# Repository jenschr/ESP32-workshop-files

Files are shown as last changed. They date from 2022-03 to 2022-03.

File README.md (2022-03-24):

# ESP32-workshop-files
Kicad files from my two-day workshop at [Bitraf](https://github.com/bitraf) on creating an ESP32 based IoT device from scratch. In the Workshop, attendees will be making an IoT device from scratch using the Open Source EDA software Kicad. [Slides from the workshop](https://www.slideshare.net/jensa/two-day-electronics-workshop-with-kicad-training) can be found at my Slideshare account.

## Reference designs
In the workshop, we'll create our own boards from scratch, but we found that it's convenient to have a project to compare and check things against. In the workshop, the attendees can choose to use either the ESP32 S2/S3 Mini or the ESP32 Wroom 32E modules. The latter requires the use of a serial chip such as the CP2102/04 and this tested design has the required auto-program circuitry.

## Alternate parts
Having a devboard is fun, but having some builtin input and output is even better, so for the attendees that don't have a plan, I've suggested to add an APA102 Dotstar pixel as well as a simple NTC-based temperature sensor. The circuit for these two are in the files for the S2/S3 Mini.

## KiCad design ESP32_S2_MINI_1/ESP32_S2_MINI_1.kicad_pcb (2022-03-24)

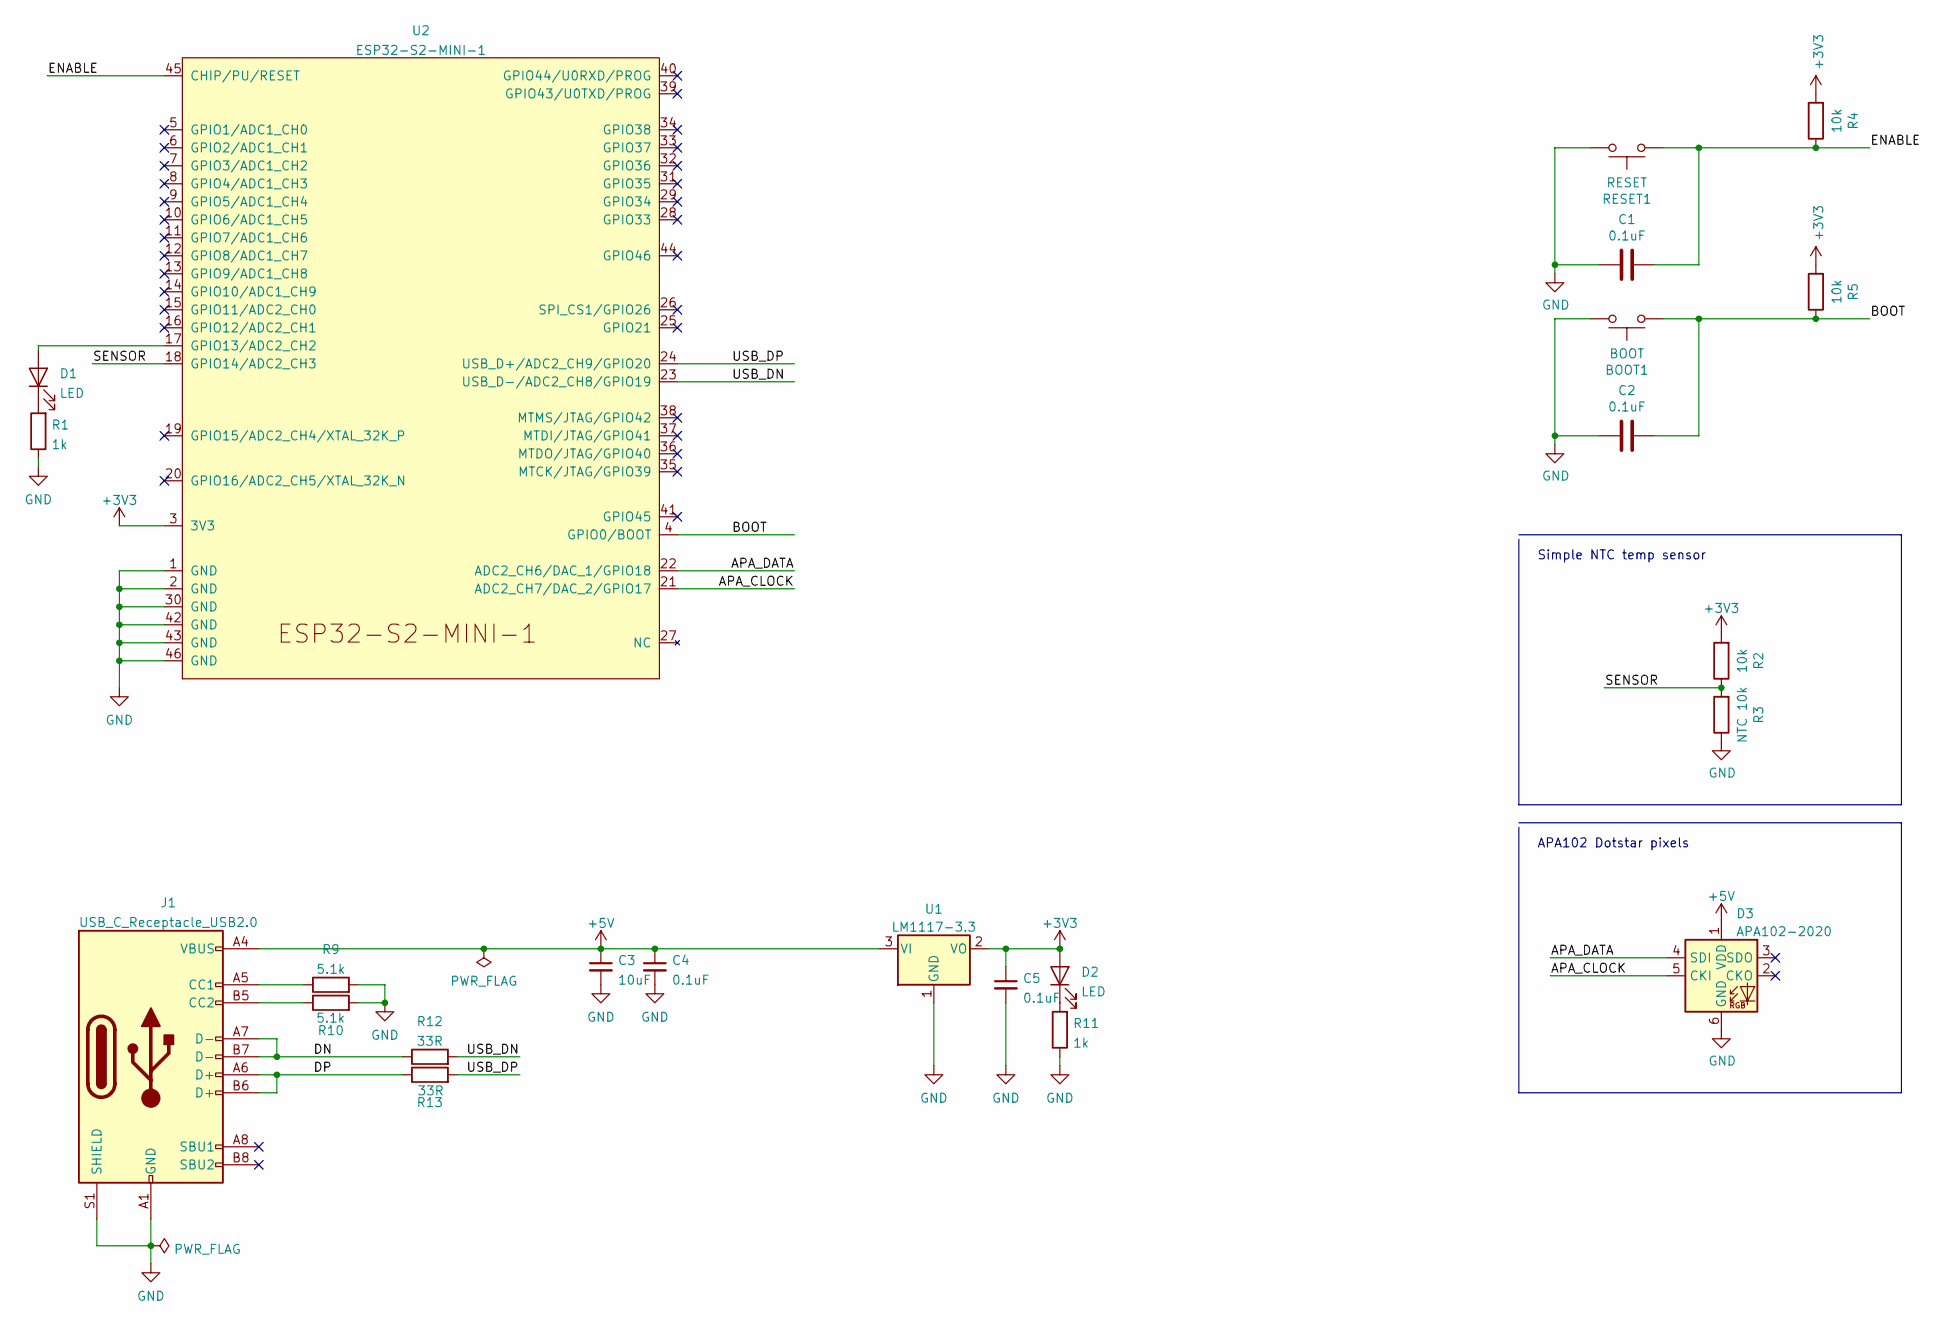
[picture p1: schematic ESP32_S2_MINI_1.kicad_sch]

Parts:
BOOT1: BOOT; SW_Push_1P1T_NO_CK_KMR2; MPN KMR241GLFS
C1, C2: 0.1uF; C_0402_1005Metric; MPN CL10B104KO8NFNC
C3: 10uF; C_0603_1608Metric
C4, C5: 0.1uF; C_0402_1005Metric
D1, D2: LED; LED_0402_1005Metric
D3: APA102-2020; LED-APA102-2020
J1: USB_C_Receptacle_USB2.0; TYPE-C-31-M-14
R1, R11: 1k; R_0402_1005Metric
R2, R4, R5: 10k; R_0402_1005Metric; MPN RMCF0603JG10K0
R3: NTC 10k; R_0402_1005Metric; MPN RMCF0603JG10K0
R9, R10: 5.1k; R_0402_1005Metric
R12, R13: 33R; R_0402_1005Metric
RESET1: RESET; SW_Push_1P1T_NO_CK_KMR2; MPN KMR241GLFS
U1: LM1117-3.3; SOT-223
U2: ESP32-S2-MINI-1

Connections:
+3V3: C5.1, D2.2 (A), R2.2, R4.2, R5.2, U1.2 (VO), U2.3 (3V3)
+5V: C3.1, C4.1, D3.1 (VDD), J1.A4 (VBUS), J1.A9 (VBUS), J1.B4 (VBUS), J1.B9 (VBUS), U1.3 (VI)
/APA_CLOCK: D3.5 (CKI), U2.21 (ADC2_CH7/DAC_2/GPIO17)
/APA_DATA: D3.4 (SDI), U2.22 (ADC2_CH6/DAC_1/GPIO18)
/BOOT: BOOT1.1, C2.1, R5.1, U2.4 (GPIO0/BOOT)
/DN: J1.A7 (D-), J1.B7 (D-), R12.1
/DP: J1.A6 (D+), J1.B6 (D+), R13.1
/ENABLE: C1.1, R4.1, RESET1.1, U2.45 (CHIP/PU/RESET)
/SENSOR: R2.1, R3.2, U2.18 (GPIO14/ADC2_CH3)
/USB_DN: R12.2, U2.23 (USB_D-/ADC2_CH8/GPIO19)
/USB_DP: R13.2, U2.24 (USB_D+/ADC2_CH9/GPIO20)
GND: BOOT1.2, C1.2, C2.2, C3.2, C4.2, C5.2, D3.6 (GND), J1.A1 (GND), J1.A12 (GND), J1.B1 (GND), J1.B12 (GND), J1.S1 (SHIELD), R1.1, R3.1, R9.2, R10.2, R11.1, RESET1.2, U1.1 (GND), U2.1 (GND), U2.2 (GND), U2.30 (GND), U2.42 (GND), U2.43 (GND), U2.46 (GND)
unnamed: D1.1 (K), R1.2
unnamed: D1.2 (A), U2.17 (GPIO13/ADC2_CH2)
unnamed: D2.1 (K), R11.2
unnamed: J1.A5 (CC1), R9.1
unnamed: J1.B5 (CC2), R10.1

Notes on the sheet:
Simple NTC temp sensor
APA102 Dotstar pixels

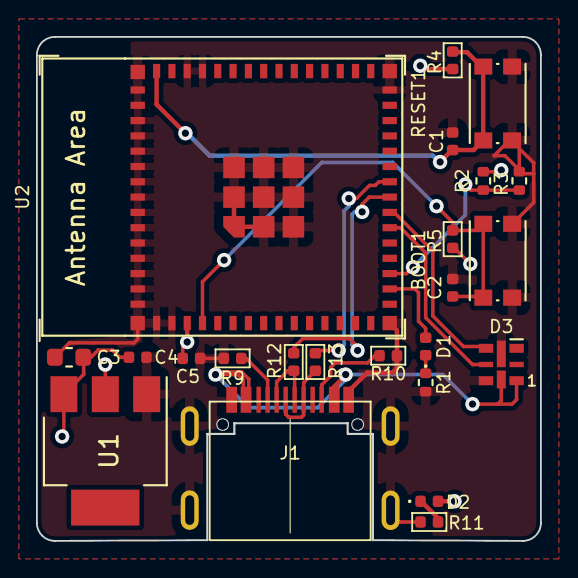
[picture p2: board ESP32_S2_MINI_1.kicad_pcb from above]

Board: 2 copper layers, 28.0 x 28.0 mm, 23 parts (0 on the bottom side), 17 nets.

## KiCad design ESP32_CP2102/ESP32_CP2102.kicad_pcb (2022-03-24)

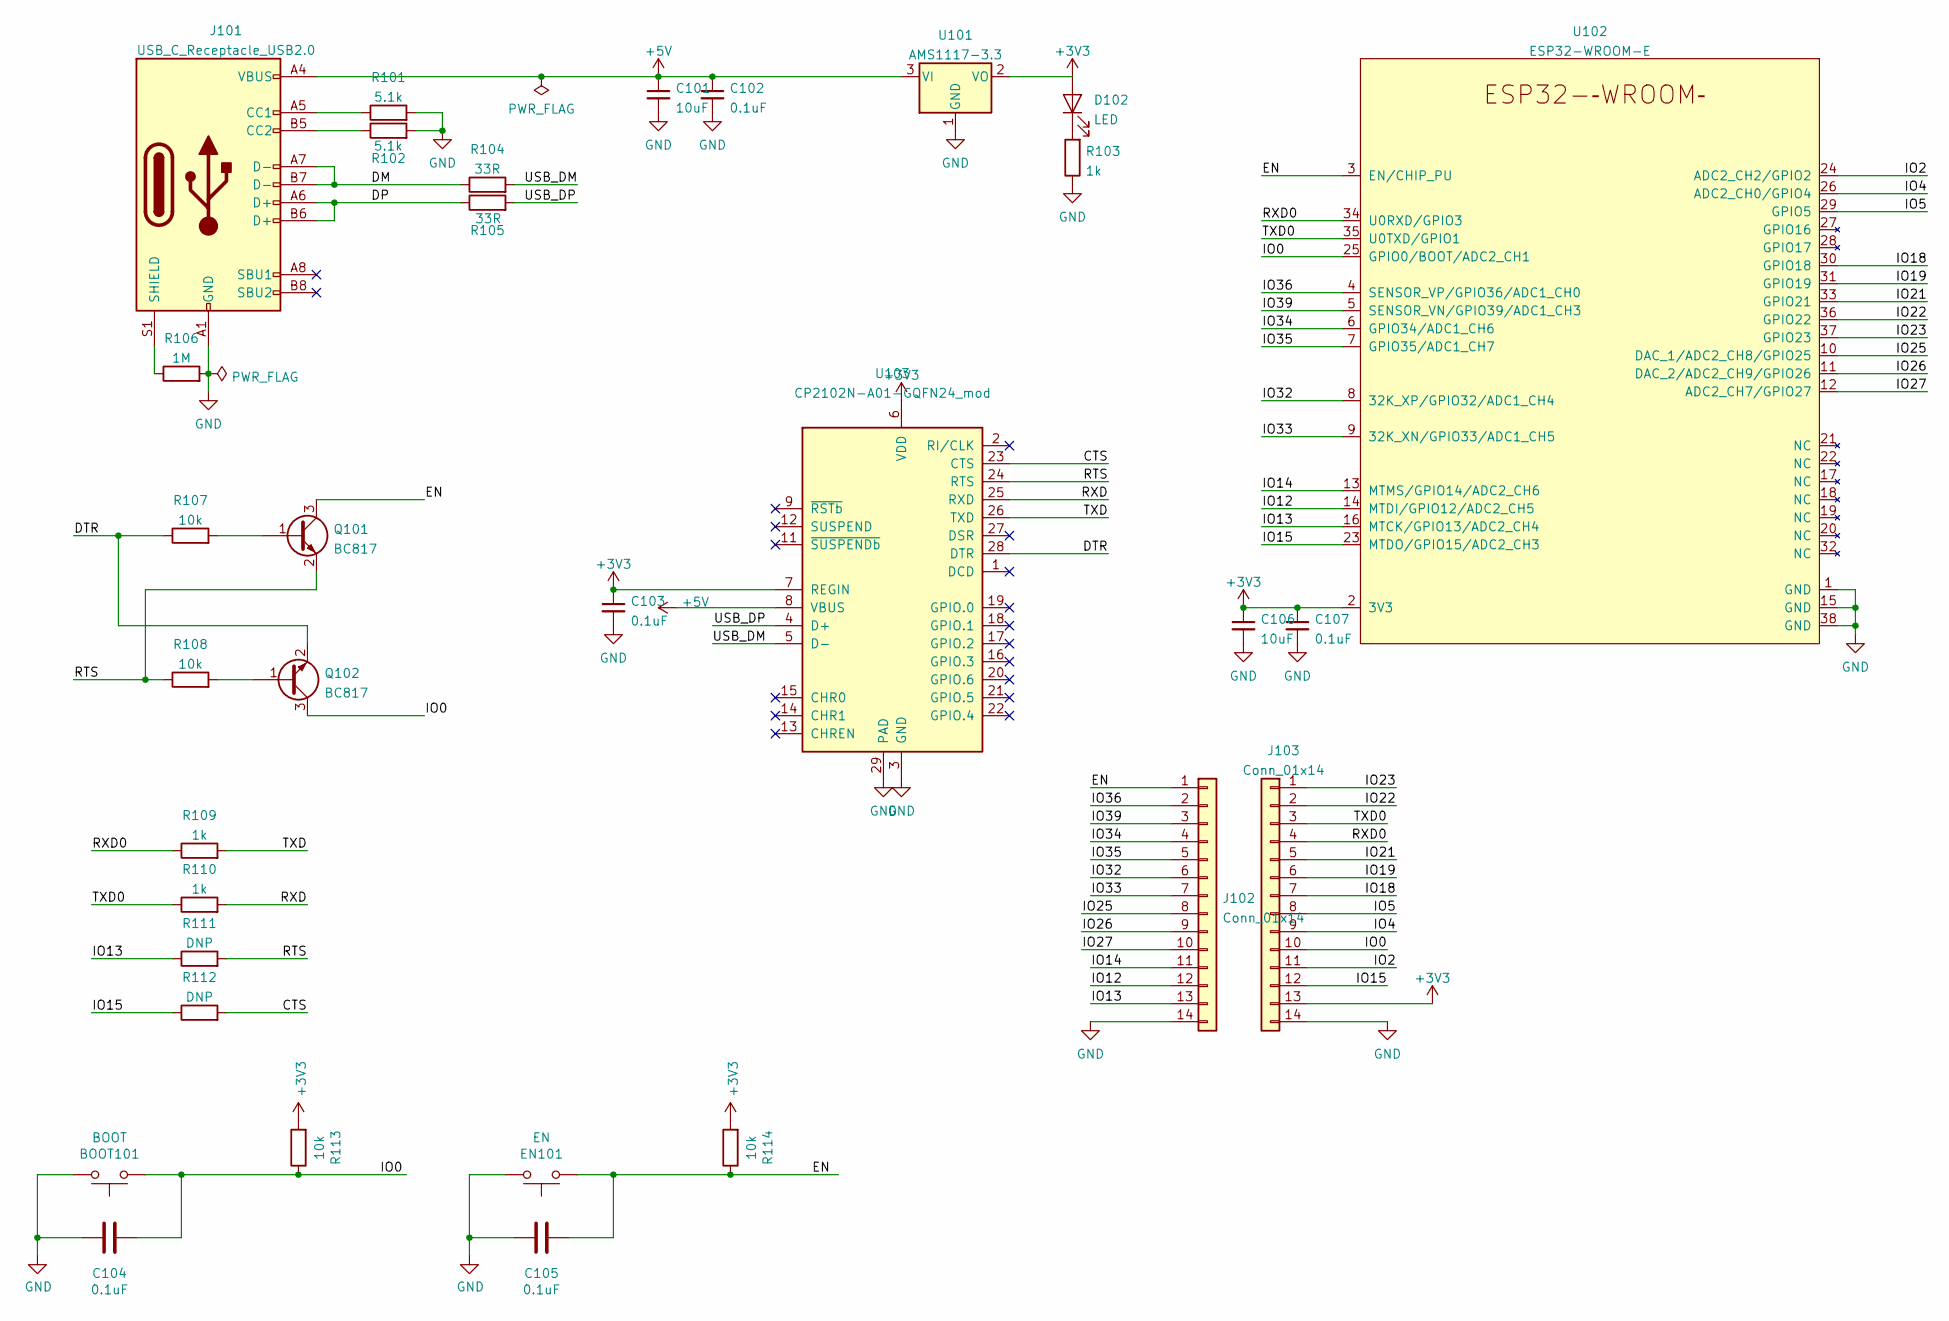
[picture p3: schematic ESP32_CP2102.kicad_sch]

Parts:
BOOT101: BOOT; KMR241GLFS; MPN KMR241GLFS
C101, C106: 10uF; C_0805_2012Metric
C102, C103, C107: 0.1uF; C_0603_1608Metric
C104, C105: 0.1uF; C_0603_1608Metric; MPN CL10B104KO8NFNC
D102: LED; LED_0603_1608Metric
EN101: EN; KMR241GLFS; MPN KMR241GLFS
J101: USB_C_Receptacle_USB2.0; TYPE-C-31-M-12
J102, J103: Conn_01x14; PinSocket_1x14_P2.54mm_Vertical
Q101, Q102: BC817; SOT-23
R101, R102: 5.1k; R_0603_1608Metric
R103, R109, R110: 1k; R_0603_1608Metric
R104, R105: 33R; R_0603_1608Metric
R106: 1M; R_0603_1608Metric
R107, R108: 10k; R_0603_1608Metric
R111, R112: DNP; R_0603_1608Metric
R113, R114: 10k; R_0603_1608Metric_Pad1.05x0.95mm_HandSolder; MPN RMCF0603JG10K0
U101: AMS1117-3.3; SOT-223-3_TabPin2
U102: ESP32-WROOM-E; ESP32-WROOM-32E
U103: CP2102N-A01-GQFN24_mod; QFN-28-1EP_5x5mm_P0.5mm_EP3.35x3.35mm

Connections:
+3V3: C103.1, C106.1, C107.1, D102.2 (A), J103.13, R113.2, R114.2, U101.2 (VO), U102.2 (3V3), U103.6 (VDD), U103.7 (REGIN)
+5V: C101.1, C102.1, J101.A4 (VBUS), J101.A9 (VBUS), J101.B4 (VBUS), J101.B9 (VBUS), U101.3 (VI), U103.8 (VBUS)
/CTS: R112.2, U103.23 (CTS)
/DM: J101.A7 (D-), J101.B7 (D-), R104.1
/DP: J101.A6 (D+), J101.B6 (D+), R105.1
/DTR: Q102.2 (E), R107.1, U103.28 (DTR)
/EN: C105.1, EN101.1, J102.1, Q101.3 (C), R114.1, U102.3 (EN/CHIP_PU)
/IO0: BOOT101.1, C104.1, J103.10, Q102.3 (C), R113.1, U102.25 (GPIO0/BOOT/ADC2_CH1)
/IO2: J103.11, U102.24 (ADC2_CH2/GPIO2)
/IO4: J103.9, U102.26 (ADC2_CH0/GPIO4)
/IO5: J103.8, U102.29 (GPIO5)
/IO12: J102.12, U102.14 (MTDI/GPIO12/ADC2_CH5)
/IO13: J102.13, R111.1, U102.16 (MTCK/GPIO13/ADC2_CH4)
/IO14: J102.11, U102.13 (MTMS/GPIO14/ADC2_CH6)
/IO15: J103.12, R112.1, U102.23 (MTDO/GPIO15/ADC2_CH3)
/IO18: J103.7, U102.30 (GPIO18)
/IO19: J103.6, U102.31 (GPIO19)
/IO21: J103.5, U102.33 (GPIO21)
/IO22: J103.2, U102.36 (GPIO22)
/IO23: J103.1, U102.37 (GPIO23)
/IO25: J102.8, U102.10 (DAC_1/ADC2_CH8/GPIO25)
/IO26: J102.9, U102.11 (DAC_2/ADC2_CH9/GPIO26)
/IO27: J102.10, U102.12 (ADC2_CH7/GPIO27)
/IO32: J102.6, U102.8 (32K_XP/GPIO32/ADC1_CH4)
/IO33: J102.7, U102.9 (32K_XN/GPIO33/ADC1_CH5)
/IO34: J102.4, U102.6 (GPIO34/ADC1_CH6)
/IO35: J102.5, U102.7 (GPIO35/ADC1_CH7)
/IO36: J102.2, U102.4 (SENSOR_VP/GPIO36/ADC1_CH0)
/IO39: J102.3, U102.5 (SENSOR_VN/GPIO39/ADC1_CH3)
/RTS: Q101.2 (E), R108.1, R111.2, U103.24 (RTS)
/RXD: R110.2, U103.25 (RXD)
/RXD0: J103.4, R109.1, U102.34 (U0RXD/GPIO3)
/TXD: R109.2, U103.26 (TXD)
/TXD0: J103.3, R110.1, U102.35 (U0TXD/GPIO1)
/USB_DM: R104.2, U103.5 (D-)
/USB_DP: R105.2, U103.4 (D+)
GND: BOOT101.2, C101.2, C102.2, C103.2, C104.2, C105.2, C106.2, C107.2, EN101.2, J101.A1 (GND), J101.A12 (GND), J101.B1 (GND), J101.B12 (GND), J102.14, J103.14, R101.2, R102.2, R103.1, R106.2, U101.1 (GND), U102.1 (GND), U102.15 (GND), U102.38 (GND), U103.3 (GND), U103.29 (PAD)
unnamed: D102.1 (K), R103.2
unnamed: J101.A5 (CC1), R101.1
unnamed: J101.B5 (CC2), R102.1
unnamed: J101.S1 (SHIELD), R106.1
unnamed: Q101.1 (B), R107.2
unnamed: Q102.1 (B), R108.2

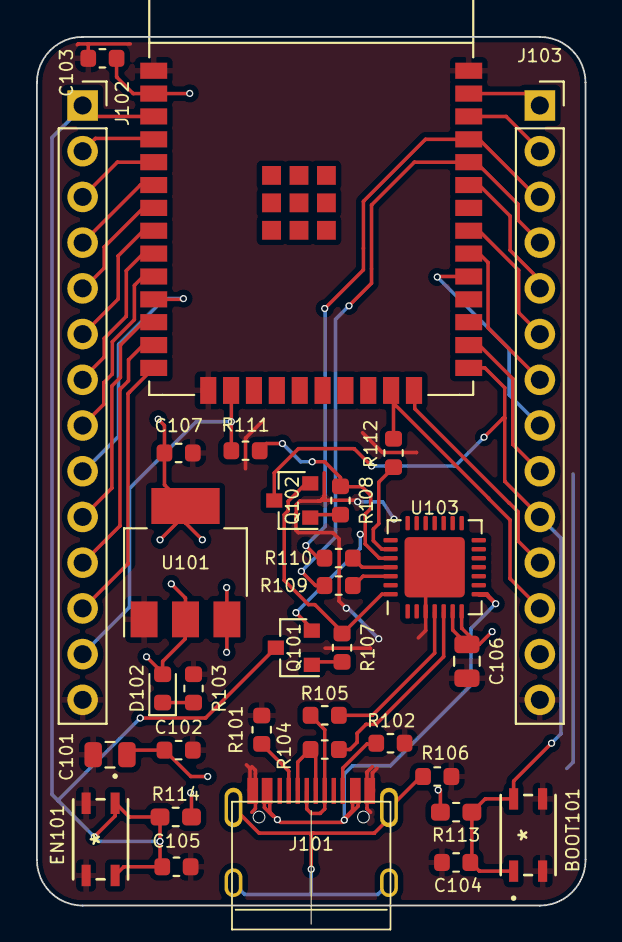
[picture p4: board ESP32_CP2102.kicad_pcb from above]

Board: 2 copper layers, 30.5 x 48.3 mm, 32 parts (0 on the bottom side), 43 nets.

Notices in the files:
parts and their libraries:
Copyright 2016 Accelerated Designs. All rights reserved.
